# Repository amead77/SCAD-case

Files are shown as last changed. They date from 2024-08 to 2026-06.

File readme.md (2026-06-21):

## Parameterized Rugged Case for OpenSCAD

This project is a (mostly) fully parametric rugged-style case designed in OpenSCAD.
You can generate a complete assembly for preview, or export individual printable parts such as:

- base (with/without feet for standing on end)
- top (w/wo feet and also you can put up to 2 lines of text and an SVG image on there, 3mf/stl may also work, but untested as of today)
- latches
- handle
- seal
- hinge screw
- latch screw

The model is driven by variables in the OpenSCAD Customizer, so you can tune dimensions, wall thickness, latch geometry, hinge fit, and seal behavior for your own use case and printer tolerances.

But why? Well, I started this sometime in 2022, maybe 2021. As a direct result of fighting with Fusion 360 and a desire to unlink myself from commercial subscription software usage. This became especially important after Autodesk paywalled previously free features.

So, I decided to learn OpenSCAD. How hard can it be, right?
Anyway, I got to the point where I'd created the base, hinges, support ribs, and latch ribs. At that point I just ran out of steam. I'd created a monster. I could barely follow my own code, purely because I used a lot of hard coded points in space and 2D arrays of data points. I posted to Reddit about this time, and people liked it as it created the whole base and top of the box, just lacked latches, but no one offered to assist. I removed it and put it on the back burner.

Sometime in 2024 I came back to it and started to un-frack it. But again, after a while I ran out of steam and still hadn't even created the latches.

Then came 2026, I was designing a lunchbox (don't ask) and needed a case. Well, what do you know. I have one of those already - but it wasn't finished. Nevermind, I found a couple of other OpenSCAD rugged case designs online. Except they didn't fit my requirements, had their own issues I'd need to fix, and I just didn't want to accept defeat. My choices were, fix my own, fix someone elses or use pre-modelled. Decided it probably wouldn't be hard to fix my own - what a fool!

So I returned to this. I thought I could get co-pilot to do some jobs for me, but yeah-nah, co-pilot did its usual of turning a working model into pure trash. So into the dustbin of history that branch went. I had to do it myself.

Hundreds of saves and dozens of commits later, I'd finally done what I started out to do 4 years prior. Co-pilot helped me with figuring out some positioning problems in the assembly view, but other than that, it was hard mode.

There's still plenty of things I need to fix, but for today, I'm done.
At some point I need to look into the remaining hard coded parts, also look at splitting the data point arrays into smaller segments. Either that or bypass them and use object primitives like a normal person.

## Preview

## Test box (models are here for this)

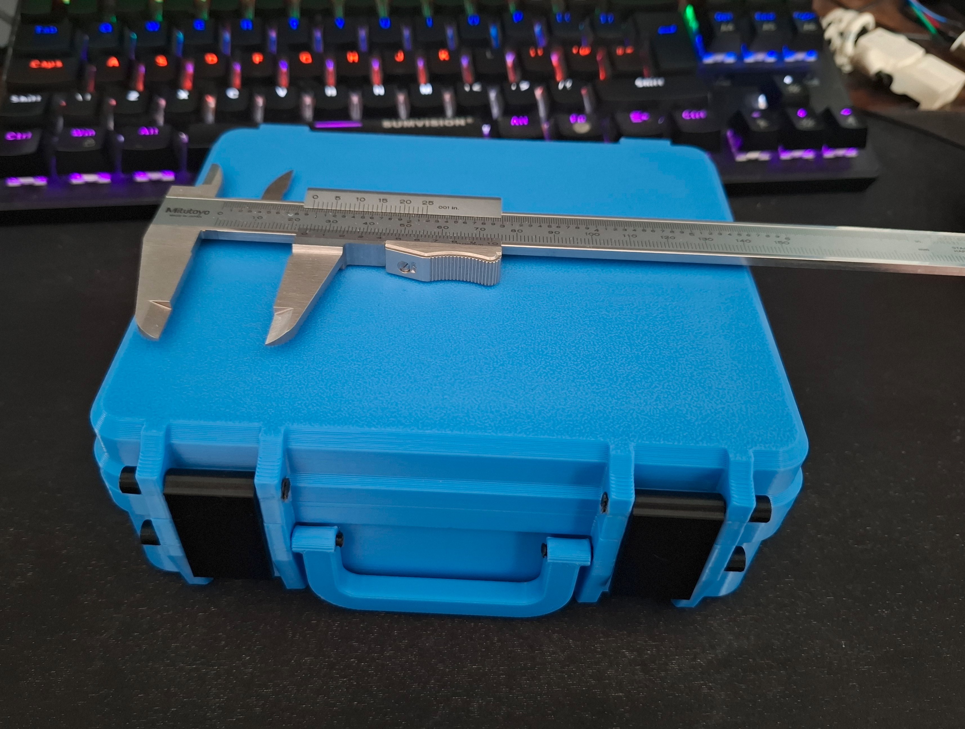
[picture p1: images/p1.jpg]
p1


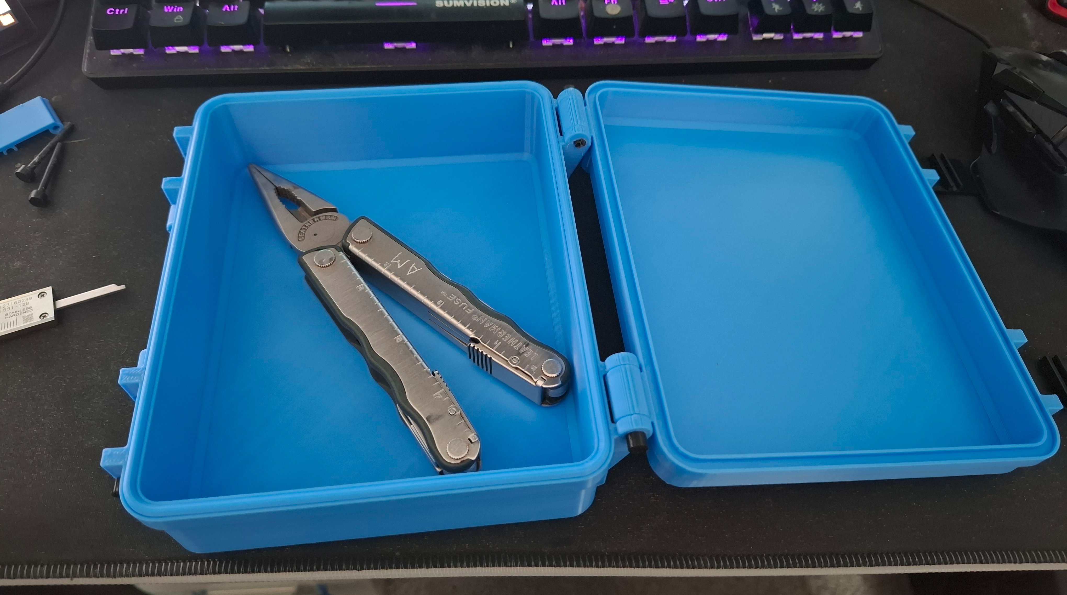
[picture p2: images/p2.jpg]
p2


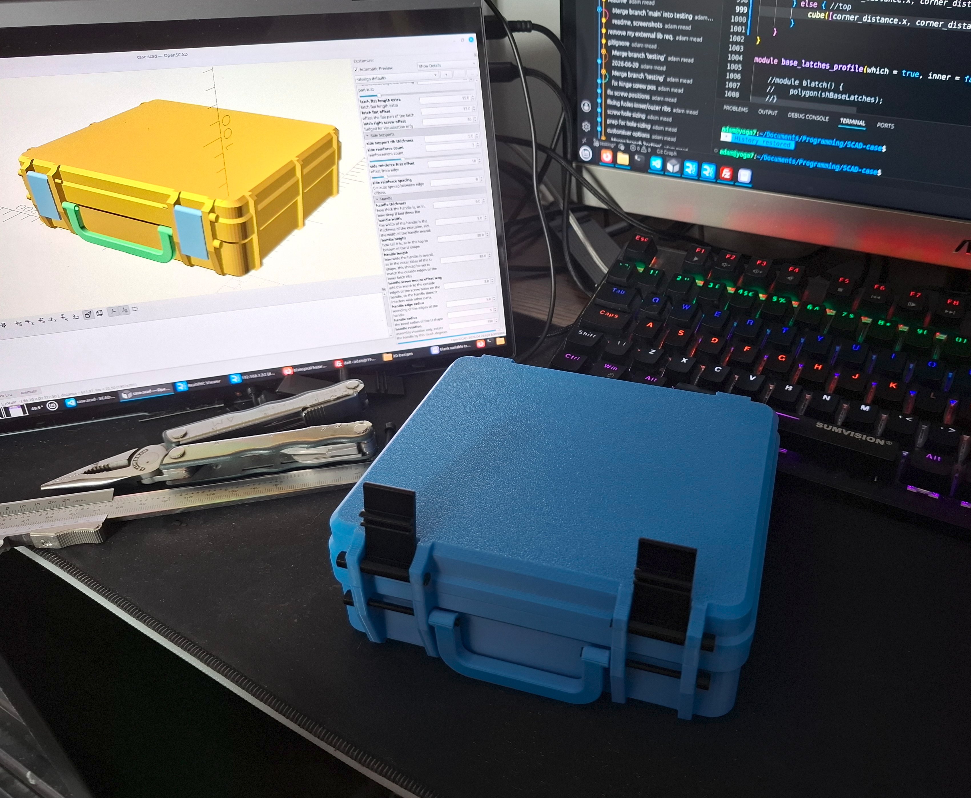
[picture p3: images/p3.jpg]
p3


### Full Assembly

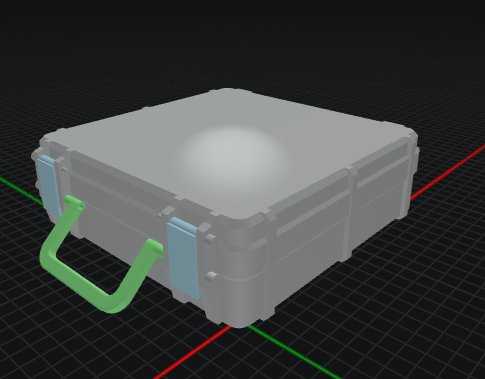
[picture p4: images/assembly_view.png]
Assembly view


### Individual Parts

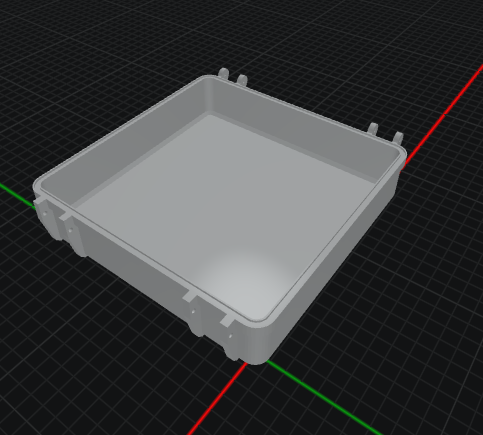
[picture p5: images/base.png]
Base part


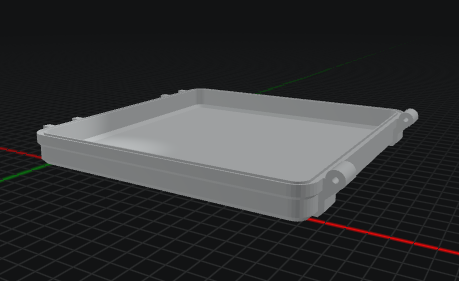
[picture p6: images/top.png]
Top part


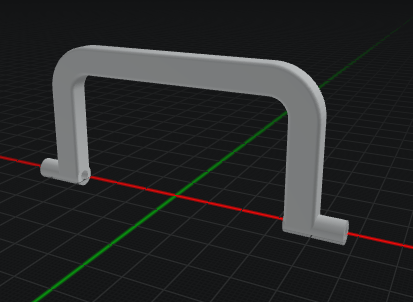
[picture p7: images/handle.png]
Handle part


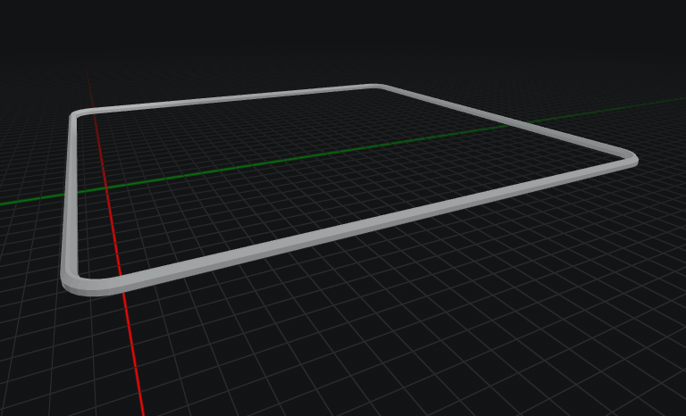
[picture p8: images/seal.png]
Seal part


Weirdly, the text/images doesn't show in assembly view. Only in the top part view. Remember to spin the lid over in openscad so you can see it.

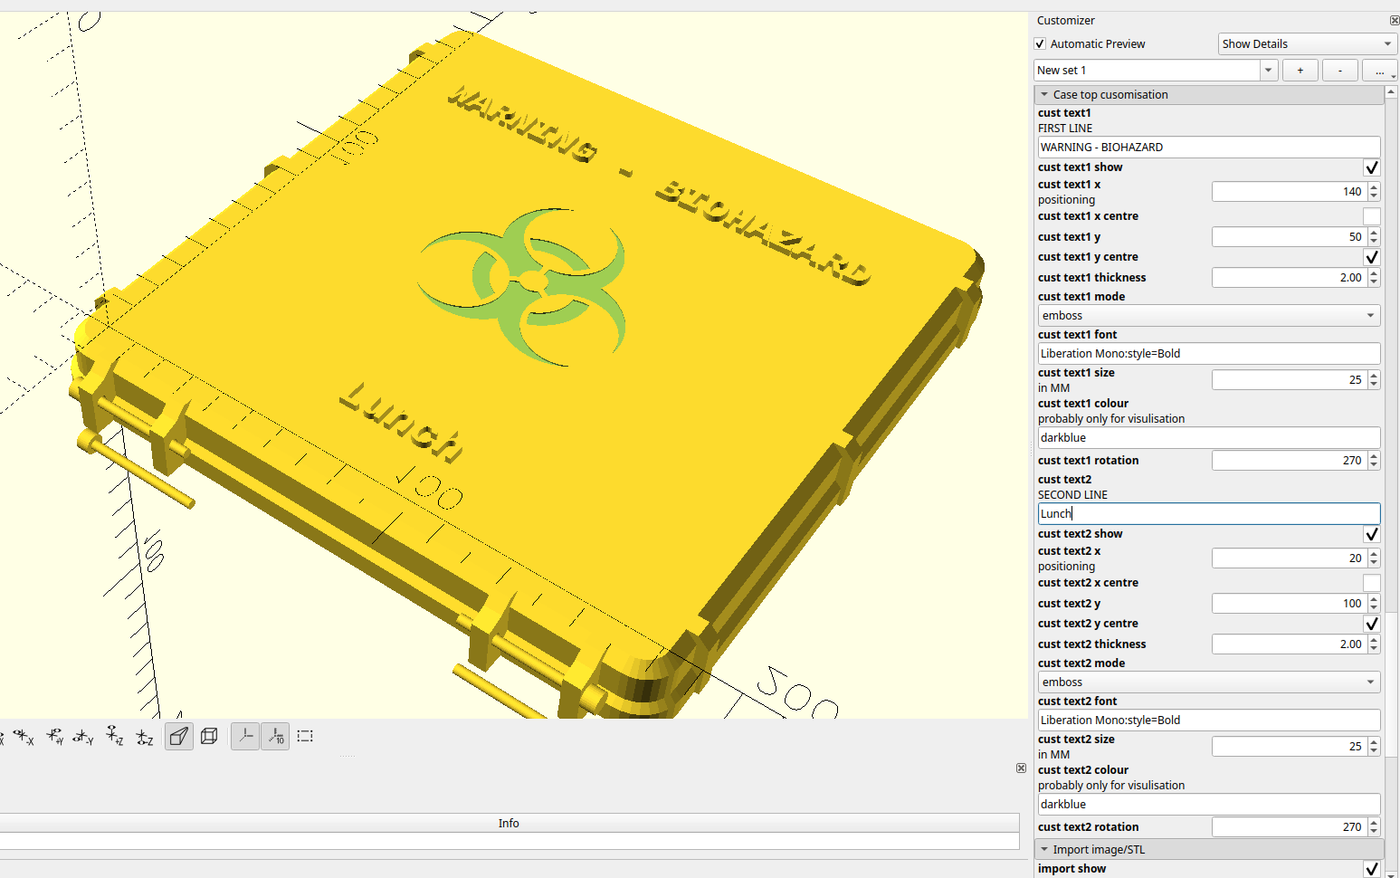
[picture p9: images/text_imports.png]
text


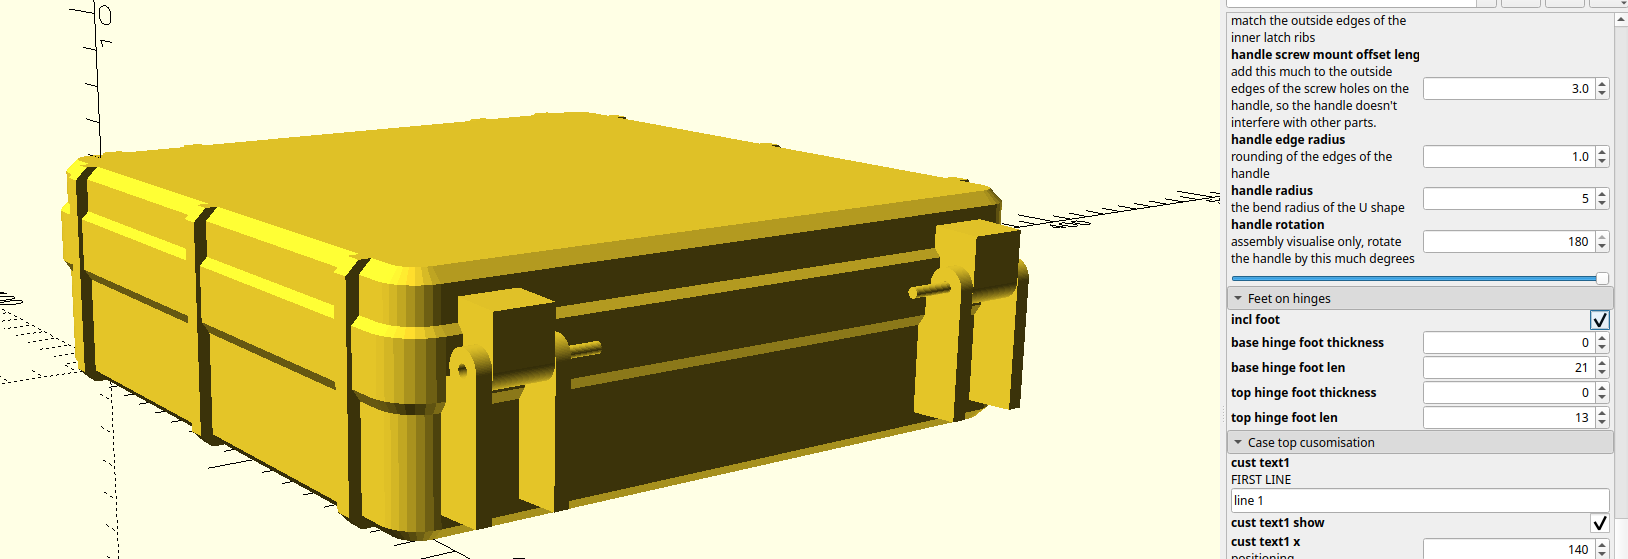
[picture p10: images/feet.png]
feet


## Quick Start

1. Open `case.scad` in OpenSCAD.
2. Open the Customizer panel.
3. Set dimensions and feature values to suit your build.
4. Choose what to generate with the `run` selector:
	- `assembly` for a full preview
	- `base`, `top`, `latches`, `handle`, `seal`, `hinge_screw`, or `latch_screw` for exportable parts
5. Render (`F6`) and export to STL or 3MF.

## Notes

- The model is intended to be edited parametrically, not by direct mesh editing.
- Fit-critical values (clearances, hole diameters, seal undersizing) may need tuning for different printers and materials.

## Support

If you like the design, you are welcome to buy me a coffee:

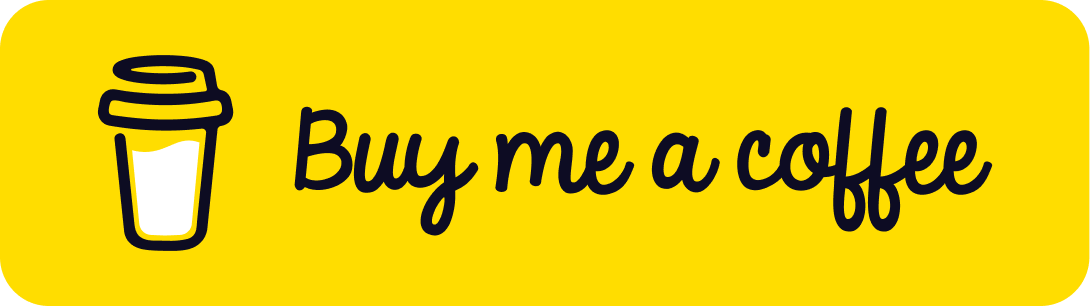
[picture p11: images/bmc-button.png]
Buy Me a Coffee


## Licence

CC – Attribution – Non-Commercial (CC BY-NC): Users can remix and build upon my model, but only for non-commercial purposes. Credit must be provided. (I literally stole this licence text)

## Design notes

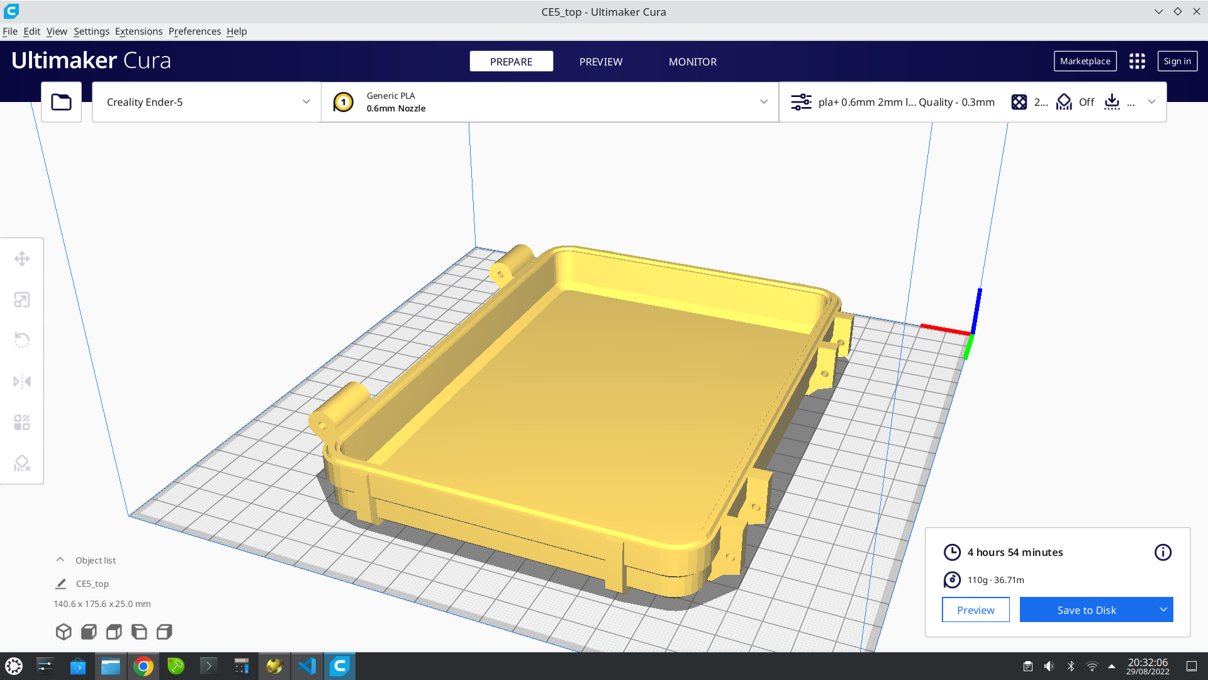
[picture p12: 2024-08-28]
Screenshot_20220829_203206.png

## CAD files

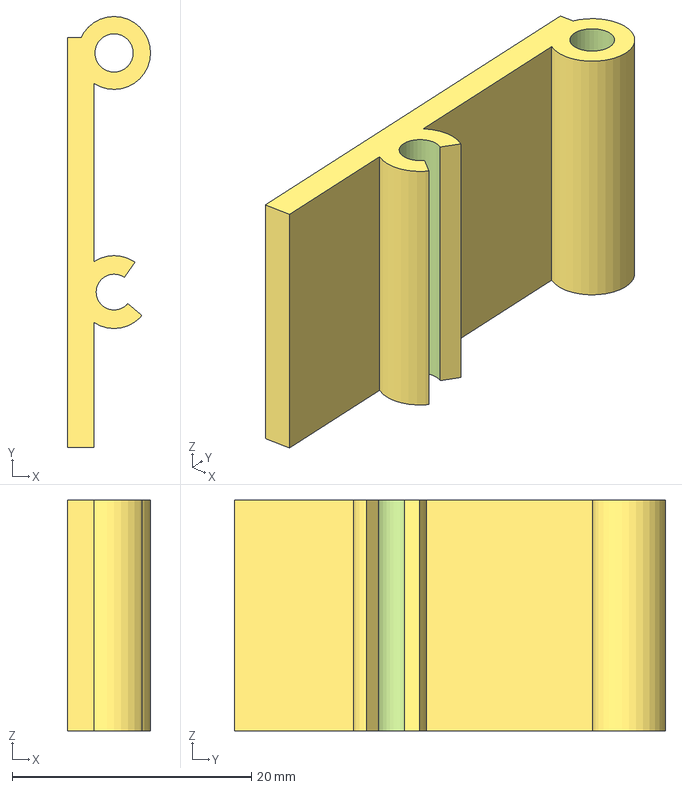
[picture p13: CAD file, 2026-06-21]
models/test latch.3mf
6.95 x 36.0 x 19.3 mm

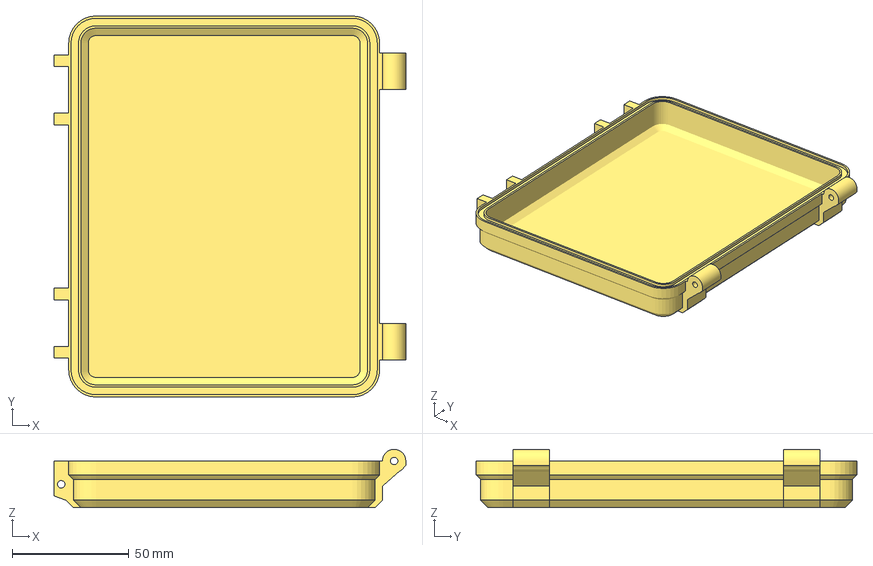
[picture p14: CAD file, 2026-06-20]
models/test top.3mf
150.6 x 163.2 x 25.0 mm

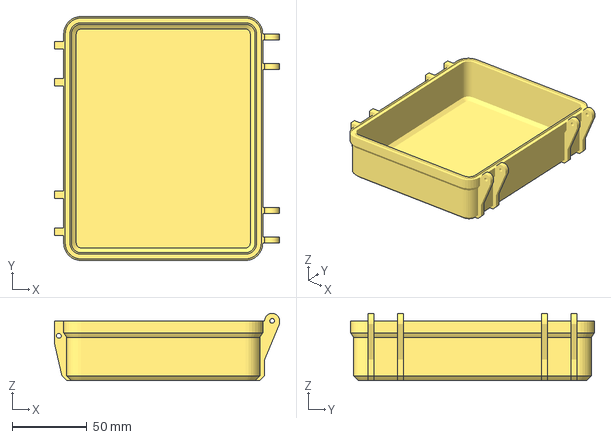
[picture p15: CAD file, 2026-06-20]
models/test base.3mf
150.6 x 163.2 x 45.0 mm

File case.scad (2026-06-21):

/*
*****[ TO DO ]*****

-fix import & text missing in assembly view. works fine in 'top' but otherwise is missing.
-case inserts. design a rounded and chamfered cube that fits in the case.
-unfrack some of the remaining hard coded parts.
-switch from 2d array of points in space to using 3d primitives. (will never happen)



*/


/*
2024
so... when I first created this (about 2 years prior) I had not long started with openscad and I stopped
creating this because I just ran out of steam before creating the latches.
I posted it to reddit in its current state and people liked it, but no one was offering
to assist, so I removed it, then abandoned the whole thing as others did a better job.
The reason I created it is the same reason I've come back to it. Autodesk Fusion 360....
You can get some really good fusion models including the design files (.f3d), but Autodesk have
gone and locked the configurator behind a paywall, where it used to be free for hobby use. 

2026
I've returned to it because I found a good one, but a) no handles, and b) creating a 80mm 
tall base caused the latches to get clipped in half. Then I found another, but that had no handles 
and other limitations. I found myself with no real option but to take another look at this.
And... oh... I made some design *choices* didn't I.
Literally no one else approached their versions like I have. Probably because they have sense.
I tried getting copilot to create my latches and fix some issues. That branch got abandoned immediately
as AI can't see what it is making and successfully produced trash. 
It can help you with syntax errors, some functions and stuff, but not create a model or part of.

as of 2026-06-20 the case is complete as is, but needs some hard-coded bits changing at a later date
*/

/**
//next 2 lines used only by my 'on save' script. can be ignored otherwise.
//AUTO-V
version = "v0.1-2026/06/21r293";
**/

//use </home/adam/Documents/Programming/SCAD-lib/mainlib.scad>;
$fn = 32;

//Choose part / Assembly view
/* [Part Chooser] */
run = "assembly"; //[assembly, base, top, latches, handle, seal, hinge_screw, latch_screw]
//In Assembly view, show these parts
show_base = true; //[true, false]
show_top = true; //[true, false]
show_handle = true; //[true, false]
show_latches = true; //[true, false]
show_screws = true; //[true, false] //current locked to top, need to refactor
show_seal = true; //[true, false]
lift_the_lid = 0; //[0:100]

/* [Basic Dimensions] */
//x,y size. This is actually to the begining of each corner radius. Design choices my dude... Render and measure edge to edge.
corner_distance = [165, 165]; 
//height of base bottom (min 20mm or it weirds out)
base_height = 40; //0.1
top_height = 20; //0.1
//muliples of nozzle size
wall_thickness = 3.2;  //0.1
//max 2x wall_thickness, chop model to see better what goes on
base_thickness = 4;  //0.1

/* [Hinge] */

//hinge hole size (legacy, replaced by hinge_outer_rib_hole_dia / hinge_inner_rib_hole_dia)
//hinge_hole = 3.2; //0.1
//thickness for outer hinge and 2x is inner hinge
hinge_thickness = 4.0; //0.1
hinge_clearance = 0.2; //0.1
//fudged for visualisation only
right_screw_offset = 35;
left_screw_offset = corner_distance.y - right_screw_offset;


/* [Screw hole sizing] */
//the top and bottom holes must match, but inner/outer can be different for screwing into the plastic on one side, top case hinge hole will match hinge_outer_rib_hole_dia
hinge_outer_rib_hole_dia = 3.2; //0.1
hinge_inner_rib_hole_dia = 3.2; //0.1

//the top case latch rib hole sizing can be differrent from the base, as adding a handle could change how you want to attach
latch_outer_rib_top_hole_dia = 3.2; //0.1
latch_inner_rib_top_hole_dia = 3.2; //0.1
latch_outer_rib_base_hole_dia = 3.2; //0.1
latch_inner_rib_base_hole_dia = 3.2; //0.1

//handle hole can be different from the latch rib holes
handle_hole_dia = 3.2; //0.1



/* [Screw/Pin sizing] */
//The latch pins. these are the screws/pins that are visualised and printable
latch_screw_dia = 2.8; //0.1
latch_screw_len = 35; //0.1
latch_screw_head_dia = 6; //0.1
latch_screw_head_len = 4; //0.1
//The hinge pins
hinge_screw_len = 25; //0.1
hinge_screw_dia = 2.8; //0.1
hinge_screw_head_dia = 6; //0.1
hinge_screw_head_len = 4; //0.1



/* [Seal and Lip] */

//changing this affects the angle of the seal outer. use for printing support ease. Min is lip_z = 8
base_lip_z = 8; //0.1
base_lip_z_angler = 3; //0.1
//same for top
top_lip_z = 8; //0.1
top_lip_z_angler = 2; //0.1

//seal depth. This will always be -1 for the top (to allow 1mm seal)
seal_depth = 1.5;
//under or oversize the seal height by this much, for fitment/different materials
seal_undersizing_z = -0.2; //0.01
seal_undersizing_inner = 0.05;//0.01
seal_undersizing_outer = 0.05;//0.01

//the width of the part at the case side
//seal_width_case = 3;
//the width of the part that sticks out
seal_width_open = wall_thickness / 4;

sd = seal_depth;
bh = base_height;
th = top_height;
wt = wall_thickness;
//swc = seal_width_case;
swo = seal_width_open;





/* [Latches] */

///////////////////come back to here
//this shouldn't change
latch_dist_between_holes = 20.0;  //0.1
latch_width = 19.5; //0.1
//how thick the screw hole part is
latch_circle_thickness = 6.1; //0.1
//too thick and it won't flex
latch_thickness = 2.2; //0.1
latch_preview_outset = latch_dist_between_holes;

//this is the clearance added/removed around that latching part. the hole size is latch rib outer
latch_screw_clip_clearance = -0.2; //0.01
latch_thickness_offset = 1.7; //0.01
//**this is the latching part of the latch, how much of a circle it is
latch_segment_angle = 265; //[0:359]
//**this is what angle the latching part is at
latch_segment_rotation = 55; //[0:359]
//latch flat length extra
latch_flat_length_extra = 15; //0.1
//offset the flat part of the latch
latch_flat_offset = 13; //0.1
//fudged for visualisation only
latch_right_screw_offset = 40;
latch_left_screw_offset = corner_distance.y - latch_right_screw_offset;

/* [Side Supports] */
side_support_rib_thickness = 5; //0.1
//reinforcement count
side_reinforce_count = 3; // [1:1:8]
//offset from edge
side_reinforce_first_offset = 10; // [4:1:60]
// 0 = auto spread between edge offsets
side_reinforce_spacing = 0; 


/* [Handle] */
handle_preview_y = (latch_left_screw_offset + latch_right_screw_offset) / 2;

//how thick the handle is, as in, how deep if laid down flat
handle_thickness = 6; //0.1
//the width of the handle is the thickness of the extrusion, not the width of the handle overall
handle_width = 8; //0.1
//how tall it is, as in the top to bottom of the U shape
handle_height = 28; //0.1
//how wide the handle is overall, as in the outer sides of the U shape. this should be set to match the outside edges of the inner latch ribs
handle_length = 88; //0.1
//add this much to the outside edges of the screw holes on the handle, so the handle doesn't interfere with other parts.
handle_screw_mount_offset_length = 3.0; //0.1
//rounding of the edges of the handle
handle_edge_radius = 1; //0.1
//the bend radius of the U shape
handle_radius = 5;
//assembly visualise only, rotate the handle by this much degrees
handle_rotation = 180; //[0:180]

/* [Feet on hinges] */
incl_foot = false; //[true, false]
base_hinge_foot_thickness = 0;
base_hinge_foot_len = 21;
top_hinge_foot_thickness = 0;
top_hinge_foot_len = 13;

/* [Case top cusomisation] */
maxx = corner_distance.x;
maxy = corner_distance.y;
echo (maxx);
echo (maxy);
//FIRST LINE
cust_text1 = "line 1";
cust_text1_show = true; //[true, false]
//positioning
cust_text1_x = 140; 
cust_text1_x_centre = false; //[true, false]
cust_text1_y = 50;
cust_text1_y_centre = true; //[true, false]
cust_text1_thickness = 2.00; //0.01
cust_text1_mode = "emboss"; //[emboss, engrave]
cust_text1_font         = "Liberation Mono:style=Bold";
//in MM
cust_text1_size         = 25;
//probably only for visulisation
cust_text1_colour = "darkblue";
cust_text1_rotation = 270;
//SECOND LINE
cust_text2 = "line 2";
cust_text2_show = true; //[true, false]
//positioning
cust_text2_x = 20; 
cust_text2_x_centre = false; //[true, false]
cust_text2_y = 100;
cust_text2_y_centre = true; //[true, false]
cust_text2_thickness = 2.00; //0.01
cust_text2_mode = "emboss"; //[emboss, engrave]
cust_text2_font         = "Liberation Mono:style=Bold";
//in MM
cust_text2_size         = 25;
//probably only for visulisation
cust_text2_colour = "darkblue";
cust_text2_rotation = 270;
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

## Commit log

2026-06-19 chop model
    [case.scad]
2026-06-19 assembly view
    [case.scad]
2026-06-19 side supports
    [case.scad]
2026-06-19 fix support rib positioning
    [case.scad]
2026-06-19 customiser update
    [case.scad]
2026-06-19 separating into top/bottom
    [case.scad]
2026-06-19 seal issues
    [case.scad]
2026-06-19 fixing lip
    [case.scad]
2026-06-19 pre-seal create
    [case.scad]
2026-06-19 seal progress
    [case.scad]
2026-06-19 seal fixed
    [case.scad]
2026-06-19 add screw visualisation
    [case.scad]
2026-06-19 latch. 4+ years to do this
    [case.scad]
2026-06-19 adjust latch
    [case.scad, test base.3mf, test latch.3mf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]
2026-06-19 minor adj.
    [case.scad]
2026-06-20 begin handle
    [case.scad]
2026-06-20 u shape of handle
    [case.scad]
2026-06-20 handle shape, but bugged to frack
    [case.scad]
2026-06-20 handle shape fixed
    [case.scad]
2026-06-20 add offset to handle so not interfere
    [case.scad]
2026-06-20 add handle rotation to assembly
    [case.scad]
2026-06-20 fix hinge screw in assembly view
    [case.scad]
2026-06-20 adjust defaults, fix screw sizing
    [case.scad]
2026-06-20 customiser options
    [case.scad]
2026-06-20 prep for hole sizing
    [case.scad]
2026-06-20 screw hole sizing
    [case.scad]
2026-06-20 fixing holes inner/outer ribs
    [case.scad]
2026-06-20 fix screw positions
    [case.scad]
2026-06-20 fix hinge screw pos
    [case.scad]
2026-06-20 remove my external lib req.
    [case.scad]
2026-06-21 add feet
    [case.scad, test latch.3mf]
2026-06-21 corrections to hinges
    [case.scad]
2026-06-21 engrave text
    [case.scad]
2026-06-21 emboss text
    [case.scad]
2026-06-21 text working
    [case.scad]
2026-06-21 svg import
    [case.scad]
2026-06-21 comments, todo, photos
    [case.scad]
